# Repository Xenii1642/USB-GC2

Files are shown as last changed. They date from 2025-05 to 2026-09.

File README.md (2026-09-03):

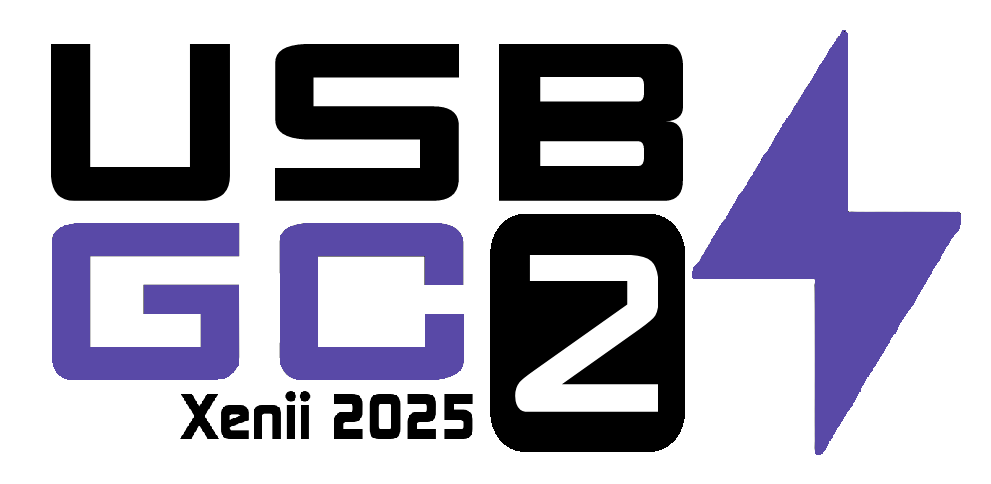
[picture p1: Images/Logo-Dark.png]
<picture> <source media="(prefers-color-scheme: dark)" srcset="Images/Logo-Light.png" width="800">  </picture> 

USB-GC2 is new generation GameCube Power Board. It allows powering the console with USB-C Power Delivery.
It also contains a switch to select between 12V or 15V input, making it compatible with a variety of Power Delivery chargers.
This second revision also integrates securities, which protects the GameCube against voltage spikes.
But most importantly, USB-GC2 is now open-source!

Check this Bitbuilt Thread for further informations: [BitBuilt Thread](https://bitbuilt.net/forums/index.php?threads/usb-gc2-next-gen-gamecube-power-board.6925/)
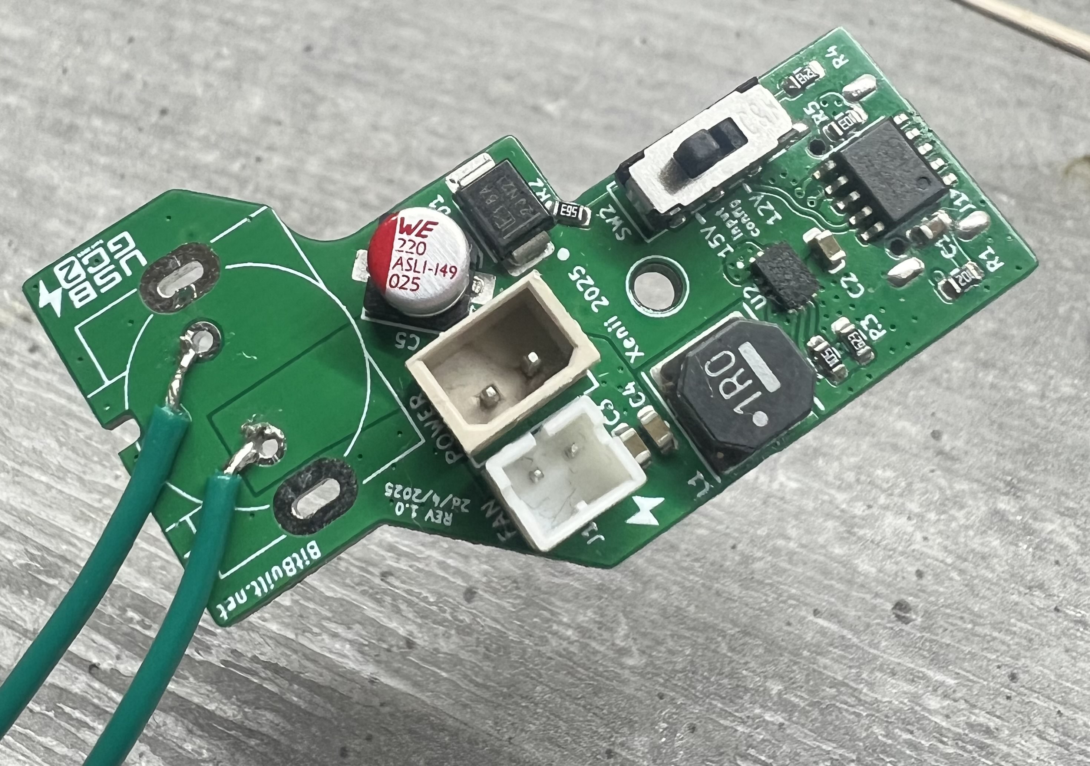
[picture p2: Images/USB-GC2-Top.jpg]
 
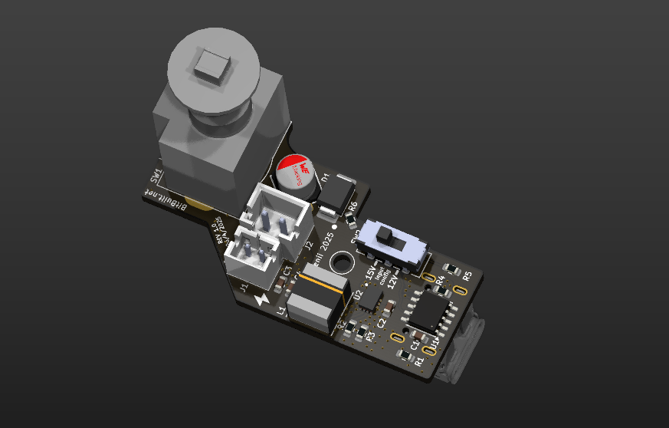
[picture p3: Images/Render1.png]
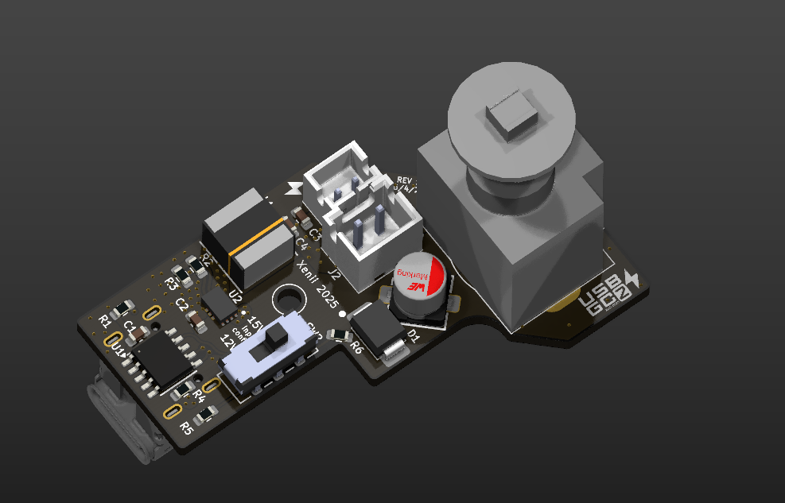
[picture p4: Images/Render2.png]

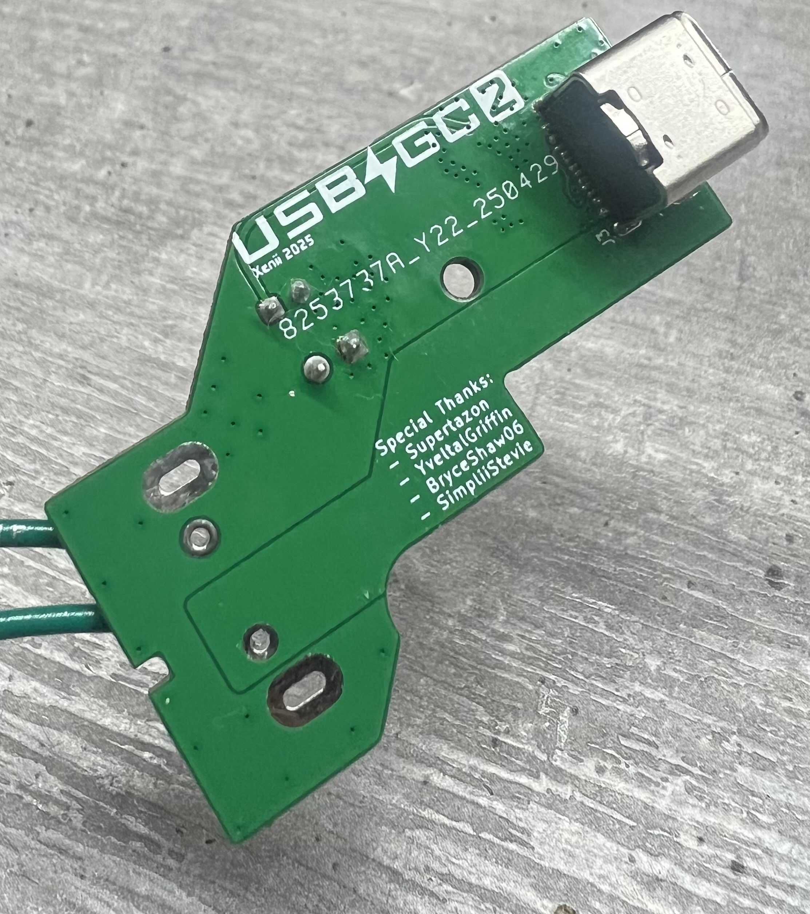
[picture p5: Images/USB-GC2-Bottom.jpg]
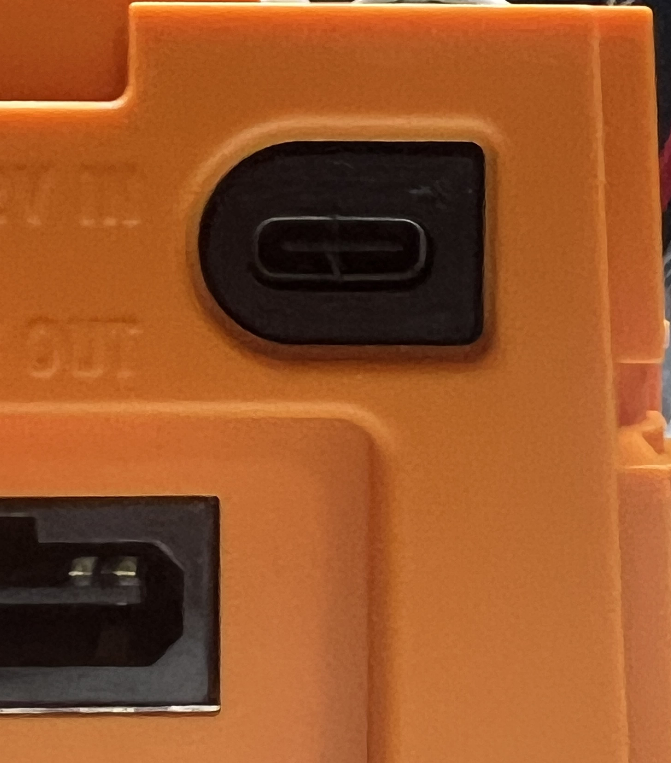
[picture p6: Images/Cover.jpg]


# PCB
USB-GC2 PCB is available in the [PCB section](https://github.com/Xenii1642/USB-GC2/tree/main/PCB) of the repository. 
Components are all listed in the [BOM file](https://github.com/Xenii1642/USB-GC2/blob/main/BOM.pdf).

### Ordering PCB:
For ordering, you can simply use the Gerber files. Upload it through your favorite manufacturer. 
I ordered mine, and personnaly suggest [JLCPCB](https://jlcpcb.com/) for that board.

For the settings, USB-GC2 doesn't need any. You should however keep the thickness to 1.6mm.
You can also change the color, it's up to you!

### Ordering components:
All the components can be ordered through Digikey or Mouser
⚠️ The links are currently only for Digikey ⚠️

# Requirements:
Except for the soldering stuff, you need a compatible USB-C Power Delivery Charger.
The charger needs to be compatible with 12V or 15V. It should also be able to deliver 2.5A of intensity.
Here are two USB-C Power Delivery chargers:

### Top charger:
Its voltage is 12V ✅
Its current is 1.67A ❌
➡️ This charger is not compatible 😭

### Bottom charger:
Voltage is 12V, but it also has 15V ✅
Current is 5A for 12V ✅
Current is 4.33A for 15V ✅
➡️ This charger is 100% compatible, and you will be able to use it with both input modes! 😊
💡 If that's the case, you should use the 12V input instead of 15V. 

# Assembling:
### PCB Assembly:
USB-GC2 PCB has been designed to be assembled in one time, using a hot plate.
My suggestion is to first apply solder paste (stencil makes life easier, you can find PCB jigs [here](https://github.com/Xenii1642/USB-GC2/blob/main/3D/USB-GC-PCB-Jig.step). Then, place the components using the [BOM file](https://github.com/Xenii1642/USB-GC2/blob/main/BOM.pdf)
I personally use BI58SN42 solder paste, but all work. Choose the one you're the most confident with 👍
Once the components are placed, I used my mini hot plate to solder everything.
It should then look like this:
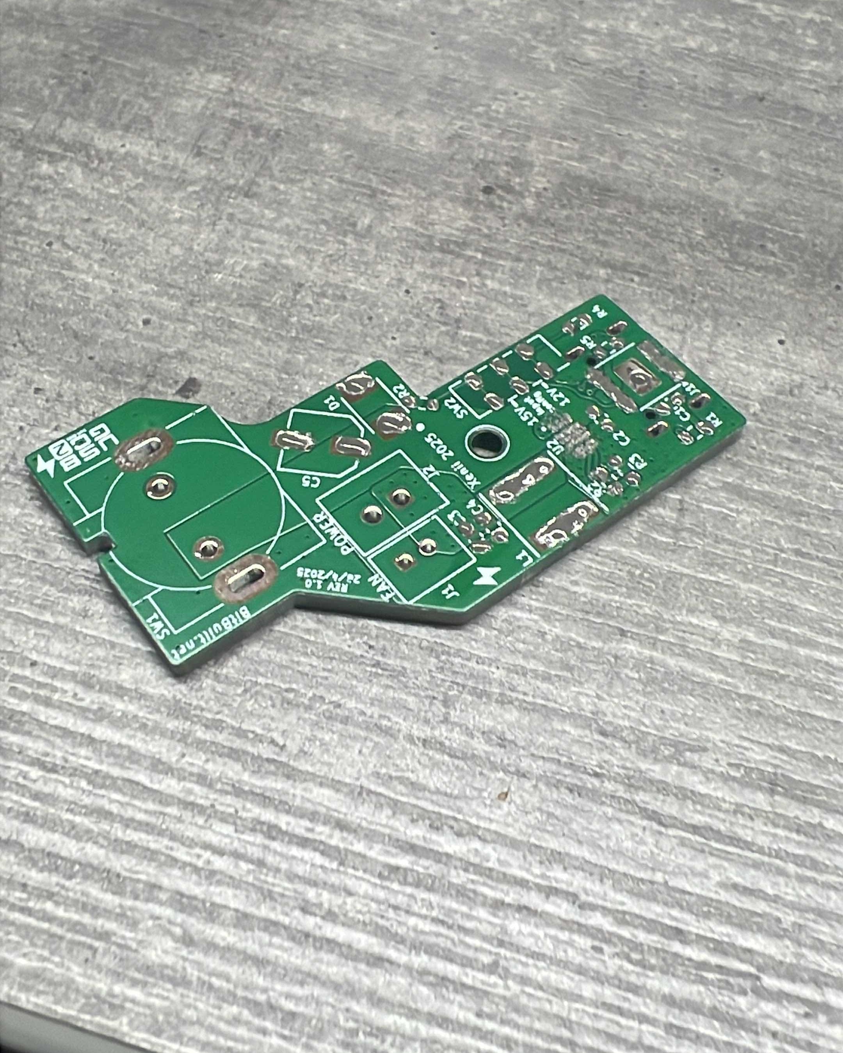
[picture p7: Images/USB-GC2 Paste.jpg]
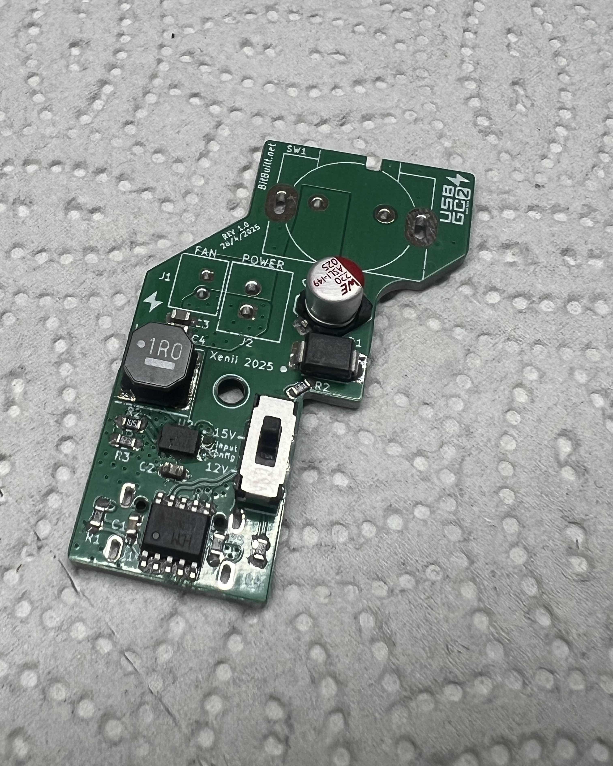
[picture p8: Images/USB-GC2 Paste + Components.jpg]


⚠️ Please take note that the original power connector (J2) and the Power Switch (SW1) should / must be took from an original board. ⚠️
💡The Step Down converter (U2) is the trickest part to solder. I just apply a really little bit of solder paste, and then apply some flux.
My recommendation is the [SMD291](https://www.digikey.com/en/products/detail/chip-quik-inc/SMD291NL/1160000)from ChipQuick.

Finally, the last step is to solder the USB-C connector. You can use hot air, but I decided to use my solder iron with the solder paste + plenty of flux.
⚠️ Do not forget to make a good clean of the board to avoid flux / solder paste making shorts between multiples pads. ⚠️

### 3D:
The USB-GC2 only needs one 3D printed cover. It is used to fill the old port and make everything prettier.
There is two version of that cover. One [with](https://github.com/Xenii1642/USB-GC2/blob/main/3D/USB-GC-Cover-Logo.step) the logo, and one [without](https://github.com/Xenii1642/USB-GC2/blob/main/3D/USB-GC-Cover.step).
If you don't have a 3D printer, you can simply order the cover through [JLC3DP](https://jlc3dp.com/).

The USB-GC2 covers are also available on my Printable account: [Printables 3D files](https://www.printables.com/model/1306430-usb-gc2)

Once printed, simply place the cover and push it against the USB-C port. Using the friction fit technology, it should stay in without moving.

### GameCube Installation:
To install the new USB-GC2 in your Nintendo GamCube console, you first need to open it up using the 3.5mm security bit.
I won't detail the whole dissasembling process here, but you can follow the [iFixit guide](https://www.ifixit.com/Guide/Nintendo+GameCube+Fan+replacement+for+cleaning/1405).

Once the original power board is removed, you can just swap the new USB-GC2 module back in.
Do not forget to plug the cables in the correct orientation.

### Testing:
Once everything is installed, simply grab a compatible USB-C Power Delivery Charger.
Plug it carefully and press the switch. You see the GameCube booting on the screen? It means it's working! Congrats!
You can now reassemble your GameCube and enjoy hours of gameplay with the same and universal charger!
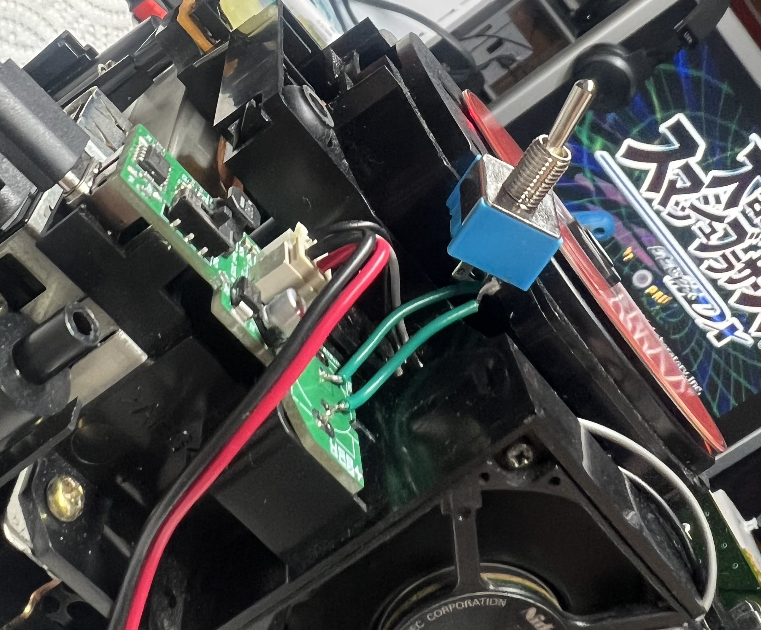
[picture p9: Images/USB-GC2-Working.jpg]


# License
The UBS-GC2 is released under the CERN-OHL-S-2.0 license. This license allows you to:
- Study
- Modify
- Manufacture
- Sell
- Distribute

Any modified versions of derivatives must also remain open-source under the same, unmodified license You must also properly credit the original creators when reusing or redistributing these files.

# Support
If you see anything wrong with the repository, the USB-GC itself, or else, please let me know.
You can also contact me for questions or suggestions!
Thanks for your support, and have fun!

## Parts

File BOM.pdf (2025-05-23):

# USB-GC2 BOM

Reference | Quantity Description | Manufacter Product Number | Link
C1 | 1 CAP CER 1UF 16V X7R 0603 | CL10B105KO8NNNC | https://www.digikey.com/en/products/detail/samsung-electro-mechanics/CL10B105KO8NNNC/3886677
C2-C4 | 3 CAP CER 10UF 25V X5R 0603 | CL10A106MA8NRNC | https://www.digikey.com/en/products/detail/samsung-electro-mechanics/CL10A106MA8NRNC/3887527
C5 | 1 CAP ALUM 22UF 20% 25V SMD | 865080442004 | https://www.digikey.com/en/products/detail/w%C3%BCrth-elektronik/865080442004/5728027
D1 | 1 TVS DIODE 15.3VWM 25.2VC SMB | SZP6SMB18AT3G | https://www.digikey.com/en/products/detail/littelfuse-inc/SZP6SMB18AT3G/3063434
J1 | 1 CONN HEADER VERT 2POS 2MM | B2B-PH-K-S | https://www.digikey.com/en/products/detail/jst-sales-america-inc/B2B-PH-K-S/926611
J2 | 1 CONN HEADER VERT 2POS 2.5MM | B2B-XH-A | https://www.digikey.com/en/products/detail/jst-sales-america-inc/B2B-XH-A/1651045
J3 | 1 CONN RCP USB2.0 TYP C 24P SMD RA | 2171800001 | https://www.digikey.com/en/products/detail/molex/2171800001/13913742
L1 | 1 FIXED IND 1UH 4.5A 18.2 MOHM SMD | NRS6045T1R0NMGK | https://www.digikey.com/en/products/detail/taiyo-yuden/NRS6045T1R0NMGK/2665987
R1 | 1 RES 1K OHM 5% 1/10W 0603 | RC0603JR-131KL | https://www.digikey.com/en/products/detail/yageo/RC0603JR-131KL/13694162
R2 | 1 RES 1M OHM 5% 1/10W 0603 | RC0603JR-071ML | https://www.digikey.com/en/products/detail/yageo/RC0603JR-071ML/726678
R3 | 1 RES 62K OHM 5% 1/10W 0603 | RC0603JR-0762KL | https://www.digikey.com/en/products/detail/yageo/RC0603JR-0762KL/726818
R4 | 1 RES 10K OHM 5% 1/10W 0603 | RC0603JR-0710KL | https://www.digikey.com/en/products/detail/yageo/RC0603JR-0710KL/726700
R5 | 1 RES 24K OHM 5% 1/10W 0603 | RC0603JR-0724KL | https://www.digikey.com/en/products/detail/yageo/RC0603JR-0724KL/726748
R6 | 1 RES 56K OHM 5% 1/10W 0603 | RC0603JR-0756KL | https://www.digikey.com/en/products/detail/yageo/RC0603JR-0756KL/726808
SW1 | 1 Nintendo GameCube Power Switch | - | You need to reuse the official one.
SW2 | 1 SWITCH SLIDE DPDT 300MA 6V | JS202011JCQN | https://www.digikey.com/en/products/detail/c-k/JS202011JCQN/6137630
U1 | 1 USB-C Power Delivery IC | CH224K | https://www.aliexpress.com/item/1005005284290184.html
U2 | 1 IC REG BUCK ADJ 4A 11VQFN | TPS621351RGXR | https://www.digikey.com/en/products/detail/texas-instruments/TPS621351RGXR/6217857

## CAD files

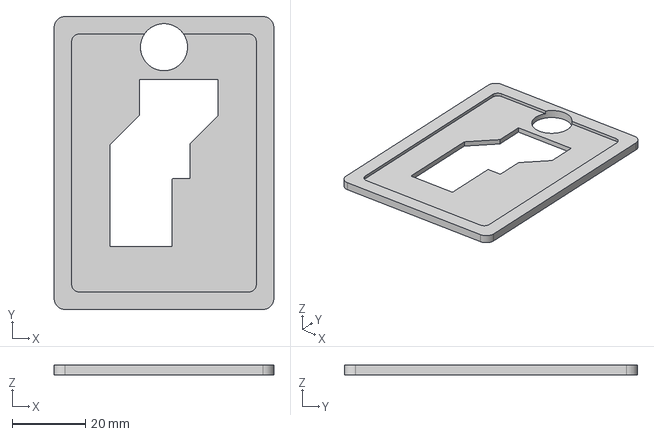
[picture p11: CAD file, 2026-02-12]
3D/USB-GC-PCB-Jig.step
60.0 x 80.0 x 2.60 mm

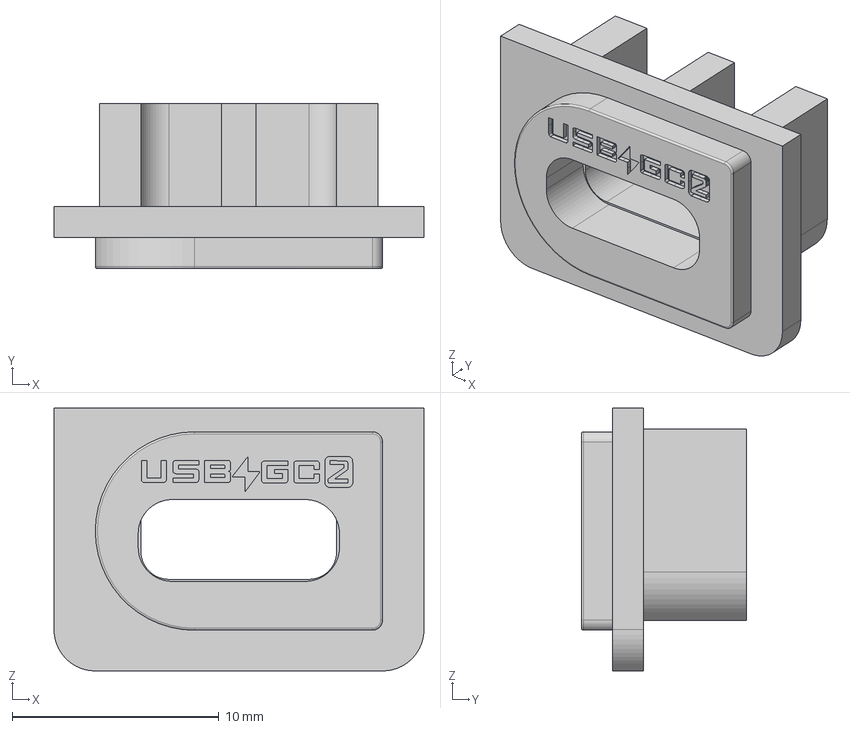
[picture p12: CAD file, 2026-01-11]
3D/USB-GC-Cover-Logo.step
17.9 x 8.00 x 12.7 mm

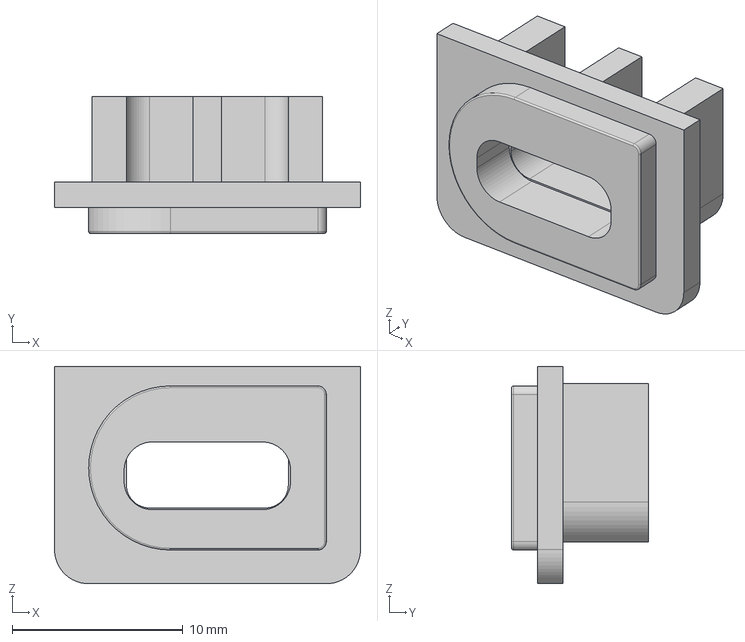
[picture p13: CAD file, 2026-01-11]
3D/USB-GC-Cover.step
17.9 x 8.00 x 12.7 mm

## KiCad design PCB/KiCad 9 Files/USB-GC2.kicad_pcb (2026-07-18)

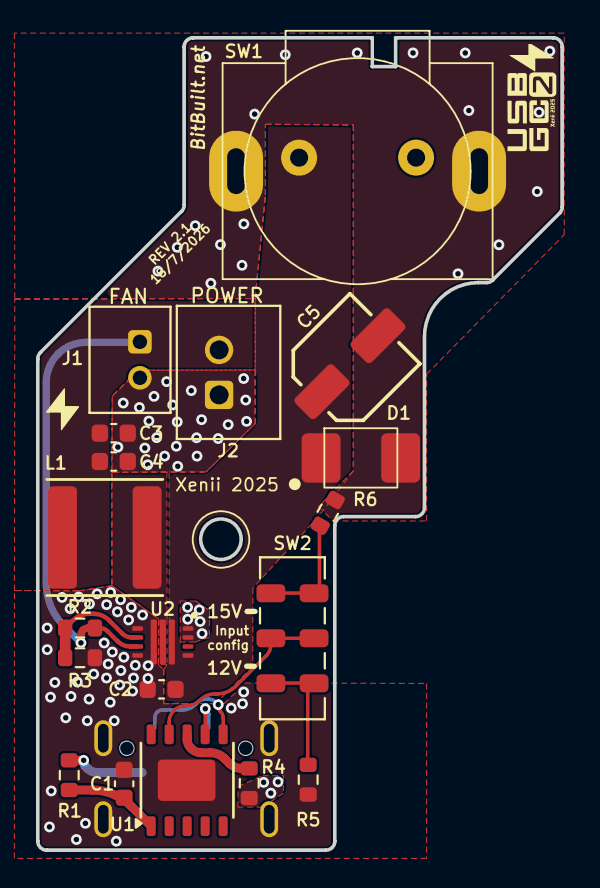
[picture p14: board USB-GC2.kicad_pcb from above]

Board: 2 copper layers, 29.1 x 45.1 mm, 20 parts (1 on the bottom side), 13 nets.

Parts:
C1: 1uF; C_0603_1608Metric
C2, C3, C4: 10uF; C_0603_1608Metric
C5: 22uF; 865080442004
D1: 20V; TVS Diode
J1: B2B-PH-K-S; JST_B2B-PH-K-S
J2: 2171800001; MOLEX_2171800001
J3: B2B-XH-A; JST_B2B-XH-A
L1: 1uH; NRS6045T1R0NMGK
R1: 1K; R_0603_1608Metric
R2: 1M; R_0603_1608Metric
R3: 62K; R_0603_1608Metric
R4: 10K; R_0603_1608Metric
R5: 24K; R_0603_1608Metric
R6: 56K; R_0603_1608Metric
SW2: JS202011JCQN; SW_JS202011JCQN
SW2#2: GC-Power-Button
U1: CH224K; ESSOP-10
U2: TPS621351RGXR; TPS621351

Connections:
+12V: C3.1, C4.1, J1.1, J3.2, L1.2, R2.1, U2.6 (VOS)
CC1: J2.A5 (CC1), U1.7 (CC1)
CC2: J2.B5 (CC2), U1.6 (CC2)
CFG: SW2.2, SW2.6, U1.9 (CFG1)
GND: C1.2, C2.1, C3.2, C4.2, C5.2, D1.2 (A2), J1.2, J2.A1B12 (GND1), J2.B1A12 (GND2), J2.SH1 (SHIELD1), J2.SH2 (SHIELD2), J2.SH3 (SHIELD3), J2.SH4 (SHIELD4), J3.1, R3.1, R5.2, R6.2, SW2#2.SH1, SW2#2.SH2, U1.0 (GND), U2.3 (GND), U2.4 (FB2), U2.7 (PG), U2.10 (MODE), U2.11 (VSEL)
unnamed: R6.1, SW2.1, SW2.5
unnamed: R5.1, SW2.3, SW2.7
unnamed: R4.1, U1.8 (VBUS)
unnamed: C1.1, R1.2, U1.1 (VDD)
unnamed: R2.2, R3.2, U2.5 (FB)
unnamed: L1.1, U2.2 (SW)
VBUS: J2.A4B9 (VBUS1), J2.B4A9 (VBUS2), R1.1, R4.2, SW2#2.2
VCC: C2.2, C5.1, D1.1 (A1), SW2#2.1, U2.1 (VIN), U2.8 (EN)

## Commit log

2026-01-11 Fix links for USB-GC2 3D cover files
    Updated links for 3D printed cover files in README.
2026-02-12 Enhance PCB assembly instructions in README
    Updated instructions for solder paste application and added link to PCB jigs.
